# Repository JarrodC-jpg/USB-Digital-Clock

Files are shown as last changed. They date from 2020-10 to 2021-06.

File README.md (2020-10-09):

# USB-Digital-Clock
Usb powered digital clock

Written by: Jarrod Coffin

Press top or bottom button to turn off center lights

To set the time:
1. Press and hold the top button until center lights start blinking
2. Top button adjust the hour, bottom button adjust minutes
3. Press and hold top button to set time, the center lights will stop blinking
4. To back out of time set without saveing press and hold the bottom button

*Note: The time currently gaines a few seconds a day resulting in about a 1 minute time loss over the course of a few days. Still need to squash that timing bug. If you have an idea of how to fix that, create a new branch and take a shot. If it fixes the issue we will merger it to the master.

If you would like a board and parts, contact me at harris.ee.projects@gmail.com

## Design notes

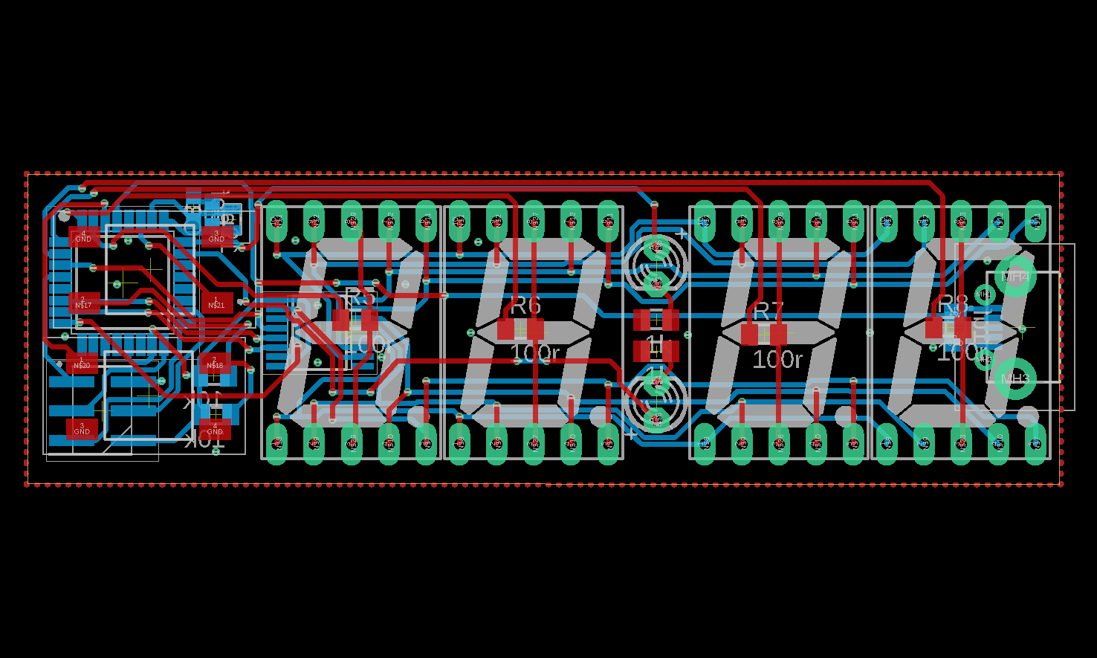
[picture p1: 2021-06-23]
Schematic and Board Files/cloclpcb.png

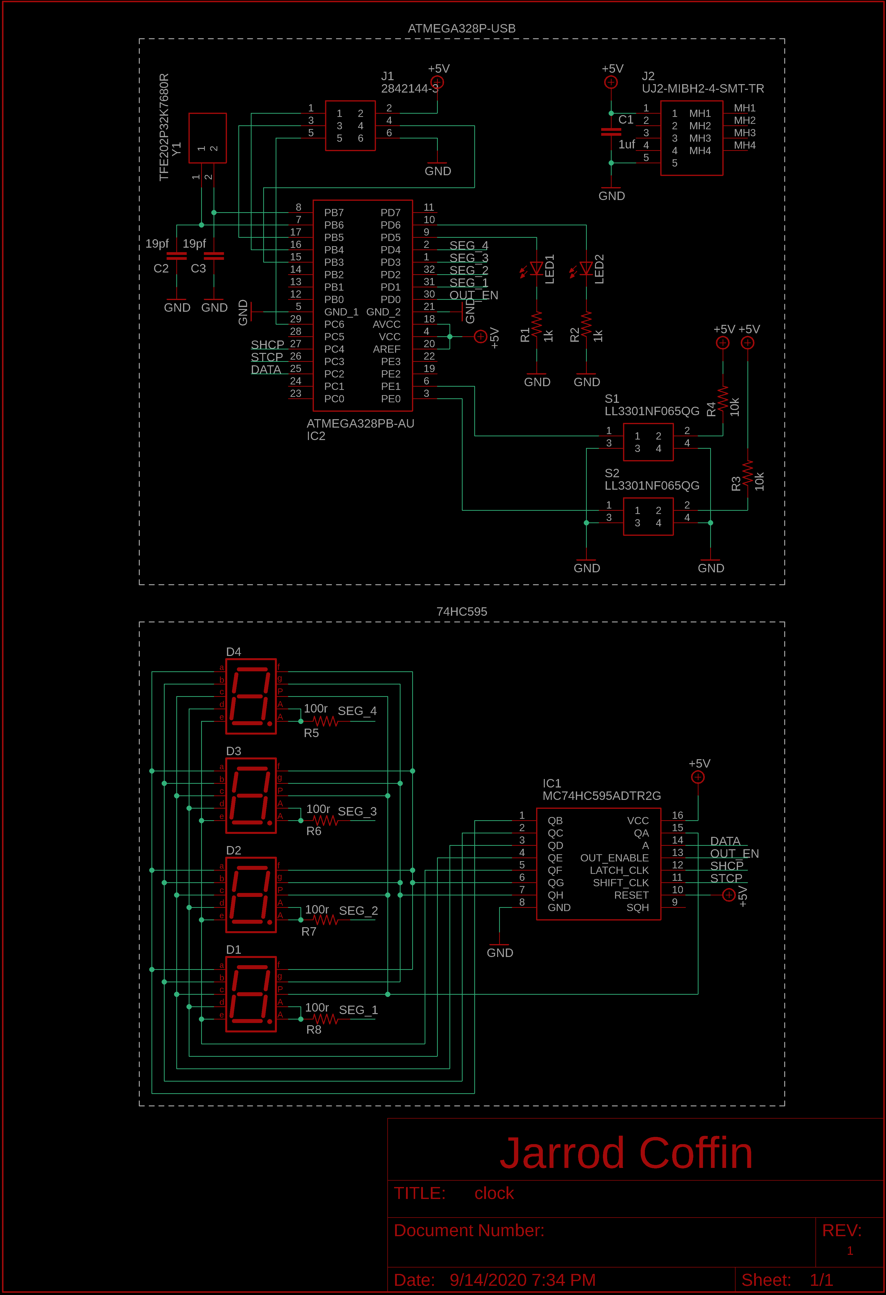
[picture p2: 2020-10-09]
Digital Clock Schem.png

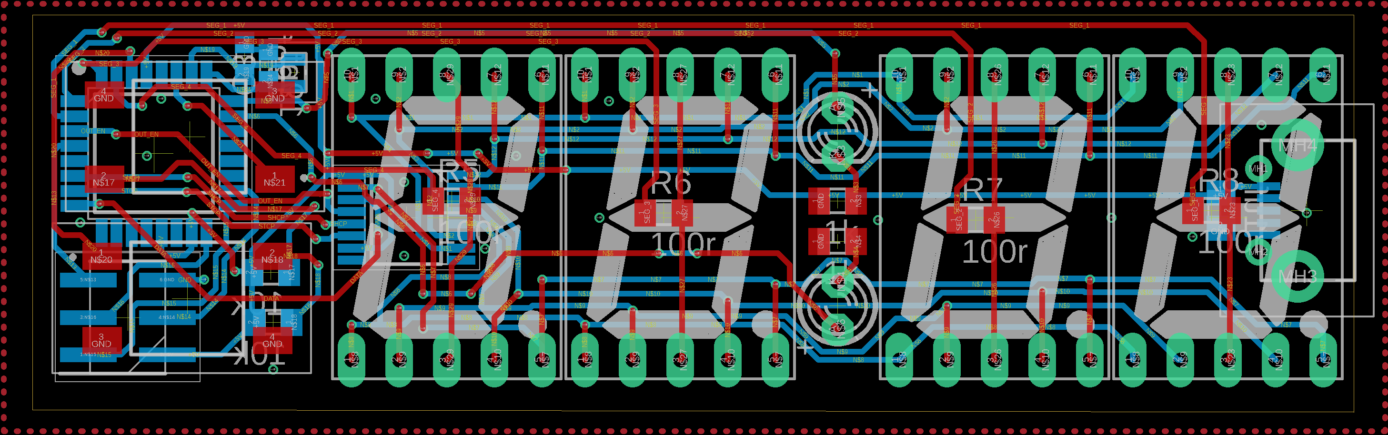
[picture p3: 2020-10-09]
Digital Clock.png

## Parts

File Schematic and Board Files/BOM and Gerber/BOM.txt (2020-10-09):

Partlist exported from Y:/EE_Projects/Clock/Clock/clock.sch at 9/14/2020 6:51 PM

Qty Value              Device             Package                        Parts          Description                                                                                                                          ARROW_PART_NUMBER  ARROW_PRICE-STOCK                                                     DESCRIPTION                                                                                                                          HEIGHT MANUFACTURER_NAME MANUFACTURER_PART_NUMBER MOUSER_PART_NUMBER  MOUSER_PRICE-STOCK                                                                                               POPULARITY SPICEPREFIX
4                      7SEG-CA            7SEG-13                        D1, D2, D3, D4 7-segment DISPLAY                                                                                                                                                                                                                                                                                                                                                                                                                                                                                                                                                               
2                      C-EUC0603          C0603                          C2, C3         CAPACITOR, European symbol                                                                                                                                                                                                                                                                                                                                                                                                                                                                                                                                73         C          
2                      LED3MM             LED3MM                         LED1, LED2     LED                                                                                                                                                                                                                                                                                                                                                                                                                                                                                                                                                                             
4   100r               R-US_R0805         R0805                          R5, R6, R7, R8 RESISTOR, American symbol                                                                                                                                                                                                                                                                                                                                                                                                                                                                                                                                                       
2   10k                R-US_R0805         R0805                          R3, R4         RESISTOR, American symbol                                                                                                                                                                                                                                                                                                                                                                                                                                                                                                                                                       
2   1k                 R-US_R0805         R0805                          R1, R2         RESISTOR, American symbol                                                                                                                                                                                                                                                                                                                                                                                                                                                                                                                                                       
1   1uf                C-EUC0805          C0805                          C1             CAPACITOR, European symbol                                                                                                                                                                                                                                                                                                                                                                                                                                                                                                                                88         C          
1   2842144-3          2842144-3          HUSSP6W50P200_2X3_600X400X590P J1             Board to Board & Mezzanine Connectors 6P,2MM,BRK HDR,DRVT, SMD,0.76AU,TR W/CAP                                                       2842144-3                                                                                Board to Board & Mezzanine Connectors 6P,2MM,BRK HDR,DRVT, SMD,0.76AU,TR W/CAP                                                       mm     TE Connectivity   2842144-3                571-2842144-3       https://www.mouser.co.uk/ProductDetail/TE-Connectivity/2842144-3?qs=Cb2nCFKsA8oUVnOWAoq9Vg%3D%3D                                       
1   ATMEGA328PB-AU     ATMEGA328PB-AU     QFP80P900X900X120-32N          IC2            ATMEL - ATMEGA328PB-AU - MCU, 8BIT, ATMEGA, 20MHZ, TQFP-32                                                                           ATMEGA328PB-AU     https://www.arrow.com/en/products/atmega328pb-au/microchip-technology ATMEL - ATMEGA328PB-AU - MCU, 8BIT, ATMEGA, 20MHZ, TQFP-32                                                                           1.2mm  Microchip         ATMEGA328PB-AU           556-ATMEGA328PB-AU  https://www.mouser.co.uk/ProductDetail/Microchip-Technology-Atmel/ATMEGA328PB-AU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                       
2   LL3301NF065QG      LL3301NF065QG      LL3301NF065QG                  S1, S2         E-SWITCH - LL3301NF065QG - TACTILE SW, SPST, 0.05A, 12VDC, SOLDER                                                                    LL3301NF065QG                                                                            E-SWITCH - LL3301NF065QG - TACTILE SW, SPST, 0.05A, 12VDC, SOLDER                                                                    4mm    E-Switch          LL3301NF065QG            612-LL3301NF065QG   https://www.mouser.co.uk/ProductDetail/E-Switch/LL3301NF065QG?qs=QtyuwXswaQiWhwgY68YTTw%3D%3D                                          
1   MC74HC595ADTR2G    MC74HC595ADTR2G    SOP65P640X120-16N              IC1            8-Bit Shift Register SER-SER/PAR TSSOP16 MC74HC595ADTR2G, 8-stage Shift Register, Serial to Serial/Parallel, 2  6 V, 16-Pin TSSOP-16                                                                                          8-Bit Shift Register SER-SER/PAR TSSOP16 MC74HC595ADTR2G, 8-stage Shift Register, Serial to Serial/Parallel, 2  6 V, 16-Pin TSSOP-16 1.2mm  ON Semiconductor  MC74HC595ADTR2G          863-MC74HC595ADTR2G https://www.mouser.com/Search/Refine.aspx?Keyword=863-MC74HC595ADTR2G                                                                  
1   TFE202P32K7680R    TFE202P32K7680R    TFE202P32K7680R                Y1             Crystals 32.768kHz 12.5pF 20ppm -40C +85C                                                                                            TFE202P32K7680R    https://www.arrow.com/en/products/tfe202p32k7680r/cts                 Crystals 32.768kHz 12.5pF 20ppm -40C +85C                                                                                            0.6mm  CTS               TFE202P32K7680R          774-TFE202P32K7680R https://www.mouser.co.uk/ProductDetail/CTS-Electronic-Components/TFE202P32K7680R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                       
1   UJ2-MIBH2-4-SMT-TR UJ2-MIBH2-4-SMT-TR UJ2MIBH24SMTTR                 J2             CONN RCPT USB2.0 MICRO B SMD R/A                                                                                                     UJ2-MIBH2-4-SMT-TR https://www.arrow.com/en/products/uj2-mibh2-4-smt-tr/cui-devices      CONN RCPT USB2.0 MICRO B SMD R/A                                                                                                     2.5mm  CUI Devices       UJ2-MIBH2-4-SMT-TR       490-UJ2-MIBH2-4-SMT https://www.mouser.co.uk/ProductDetail/CUI-Devices/UJ2-MIBH2-4-SMT-TR?qs=5mqXD9RfOg1yxHIpPvPxvQ%3D%3D

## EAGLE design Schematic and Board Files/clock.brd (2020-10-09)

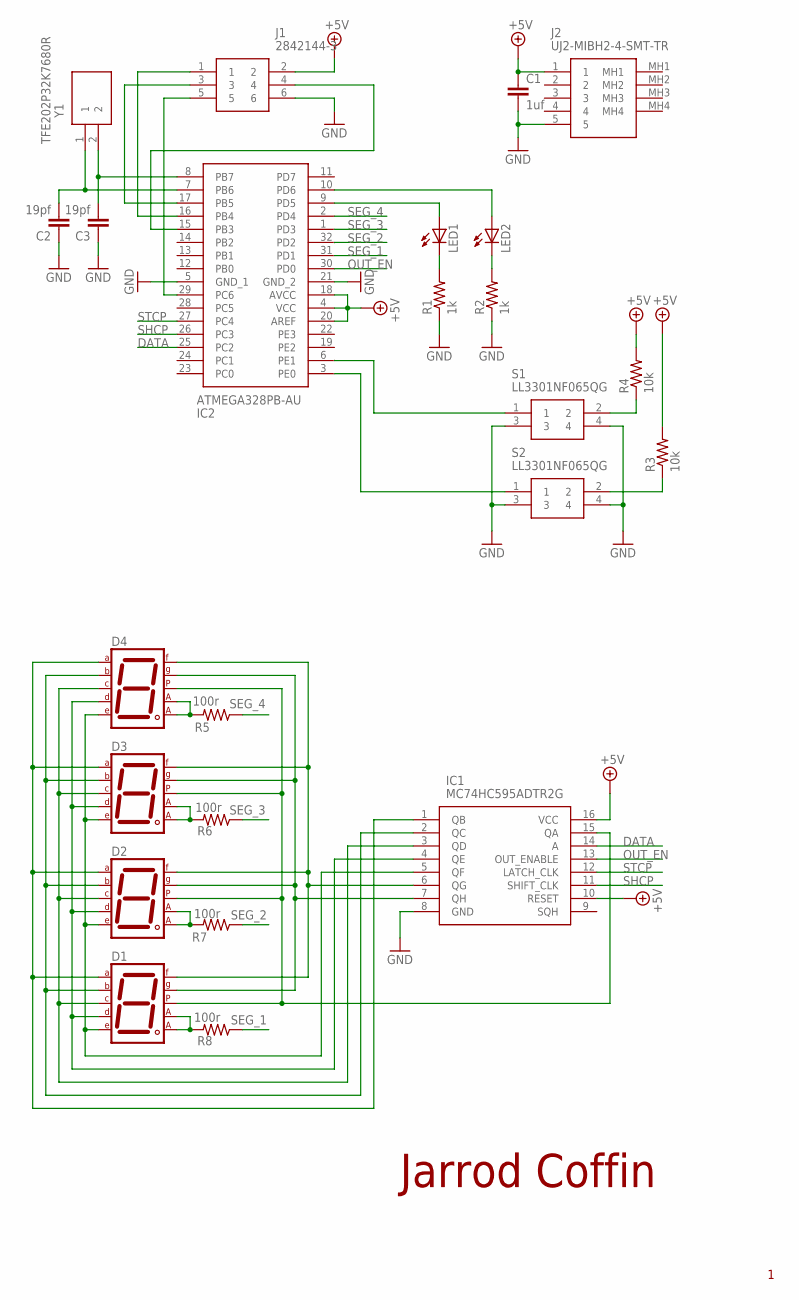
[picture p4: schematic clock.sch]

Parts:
C1: 1uf; C0805
C2, C3: 19pf; C0603
D1, D2, D3, D4: 7SEG-CA; 7SEG-13
IC1: MC74HC595ADTR2G; SOP65P640X120-16N
IC2: ATMEGA328PB-AU; QFP80P900X900X120-32N
J1: 2842144-3; HUSSP6W50P200_2X3_600X400X590P
J2: UJ2-MIBH2-4-SMT-TR; UJ2MIBH24SMTTR
LED1, LED2: LED3MM
R1, R2: 1k; R0805
R3, R4: 10k; R0805
R5, R6, R7, R8: 100r; R0805
S1, S2: LL3301NF065QG
Y1: TFE202P32K7680R

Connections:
+5V: C1.1, IC1.10 (RESET), IC1.16 (VCC), IC2.4 (VCC), IC2.18 (AVCC), IC2.20 (AREF), J1.2, J2.1, R3.2, R4.2
DATA: IC1.14 (A), IC2.25 (PC2)
GND: C1.2, C2.1, C3.1, IC1.8 (GND), IC2.5 (GND_1), IC2.21 (GND_2), J1.6, J2.5, R1.1, R2.1, S1.3, S1.4, S2.3, S2.4
unnamed: D1.10 (G), D2.10 (G), D3.10 (G), D4.10 (G), IC1.7 (QH)
unnamed: D1.9 (F), D2.9 (F), D3.9 (F), D4.9 (F), IC1.6 (QG)
unnamed: LED1.K (C), R1.2
unnamed: LED2.K (C), R2.2
unnamed: IC2.9 (PD5), LED1.A
unnamed: IC2.10 (PD6), LED2.A
unnamed: D1.5 (DP), D2.5 (DP), D3.5 (DP), D4.5 (DP), IC1.15 (QA)
unnamed: D1.1 (E), D2.1 (E), D3.1 (E), D4.1 (E), IC1.5 (QF)
unnamed: D1.2 (D), D2.2 (D), D3.2 (D), D4.2 (D), IC1.4 (QE)
unnamed: D1.4 (C), D2.4 (C), D3.4 (C), D4.4 (C), IC1.3 (QD)
unnamed: D1.6 (B), D2.6 (B), D3.6 (B), D4.6 (B), IC1.2 (QC)
unnamed: D1.7 (A), D2.7 (A), D3.7 (A), D4.7 (A), IC1.1 (QB)
unnamed: IC2.29 (PC6), J1.5
unnamed: IC2.15 (PB3), J1.4
unnamed: IC2.16 (PB4), J1.1
unnamed: IC2.17 (PB5), J1.3
unnamed: R4.1, S1.2
unnamed: R3.1, S2.2
unnamed: C2.2, IC2.7 (PB6), Y1.1
unnamed: IC2.3 (PE0), S2.1
unnamed: IC2.6 (PE1), S1.1
unnamed: D1.3 (CA1), D1.8 (CA2), R8.2
unnamed: C3.2, IC2.8 (PB7), Y1.2
unnamed: D2.3 (CA1), D2.8 (CA2), R7.2
unnamed: D3.3 (CA1), D3.8 (CA2), R6.2
unnamed: D4.3 (CA1), D4.8 (CA2), R5.2
OUT_EN: IC1.13 (OUT_ENABLE), IC2.30 (PD0)
SEG_1: IC2.31 (PD1), R8.1
SEG_2: IC2.32 (PD2), R7.1
SEG_3: IC2.1 (PD3), R6.1
SEG_4: IC2.2 (PD4), R5.1
SHCP: IC1.11 (SHIFT_CLK), IC2.26 (PC3)
STCP: IC1.12 (LATCH_CLK), IC2.27 (PC4)

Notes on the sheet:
Jarrod Coffin

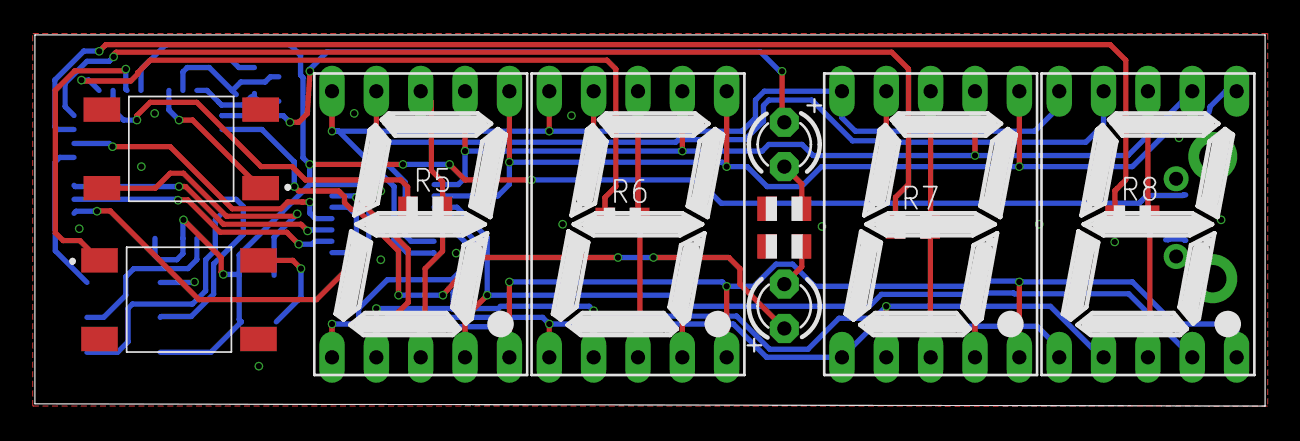
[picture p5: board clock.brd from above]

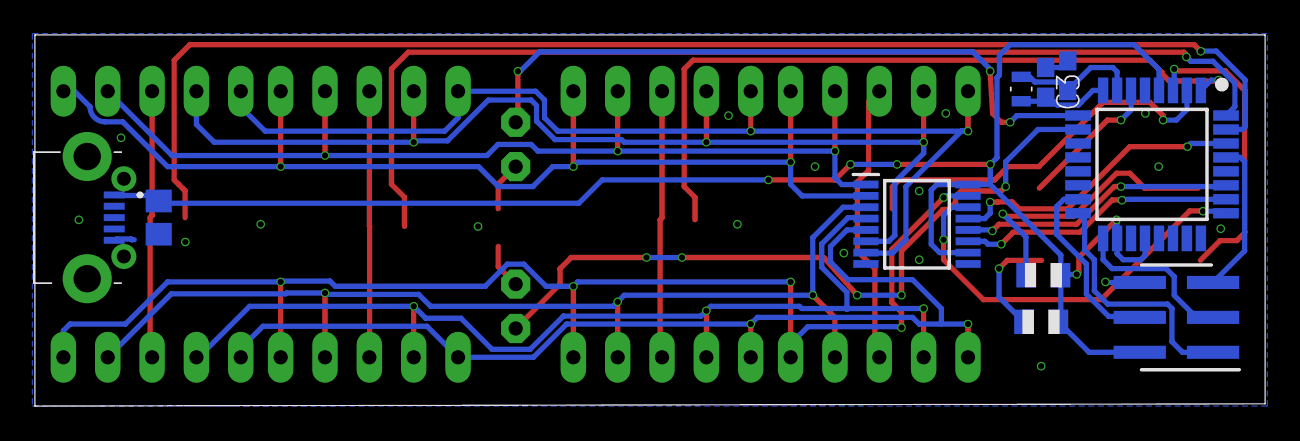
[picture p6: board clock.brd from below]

Board: 2 copper layers, 70.5 x 21.3 mm, 24 parts (10 on the bottom side), 36 nets.

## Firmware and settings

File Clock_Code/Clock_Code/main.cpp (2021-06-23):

/*
 * Clock_Code.cpp
 *
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
 * Created: 10/1/2020 1:28:43 PM
 * Author : Jarrod Coffin
 */ 

#include <avr/io.h>
#include "Includes/Header/display.h"
#include "Includes/Header/millis.h"
#include "Includes/Header/Functions.h"
#include "Includes/Header/_74HC595.h"

// Main code
int main(void)
{
	RTC_Init();
	millisInit();
	switch_init();
	init_74hc595();
	initDisp();
	blinkCOLON(OFF);
	
	uint8_t lastminutes = ~minutes;
	uint8_t lasthours = ~hours;
	uint8_t lastseconds = ~seconds;
	uint8_t dispSeconds = 0;
	uint16_t secondTimer = 0;
	uint16_t dispSecondTime = 5000;
	
    while (1) 
    {
		uint8_t press_top = switch_read(switch_top);
		uint8_t press_bottom = switch_read(switch_bottom);
		
		switch(press_top){
			
			case SINGLE:
				PORTD ^= COLON;
			break;
			
			case HOLD:
				set_time();
			break;
		
		}
		
		switch(press_bottom){
			
			case SINGLE:
				PORTD ^= COLON;
			break;
			
			case HOLD:
				dispSeconds = 1;
				secondTimer = millis;
				
			break;			
		
		}
		
		while(dispSeconds){
			if (millis - secondTimer > dispSecondTime) dispSeconds = 0;
			if (seconds != lastseconds){
				lastseconds = seconds;
				convertNum(seconds, dispSecond);
			}
			setDisp(CLEAR,CLEAR,dispSecond[1],dispSecond[0]);
		}
		
		
		if (minutes != lastminutes || hours != lasthours){
			
			lastminutes = minutes;
			lasthours = hours;
			convertNum(minutes, dispMinutes);
			convertNum(hours, dispHours);

		}
		
		if(hours < 10)setDisp(CLEAR,dispNum[dispHours[0]],dispNum[dispMinutes[1]],dispNum[dispMinutes[0]]);
		else setDisp(dispNum[dispHours[1]],dispNum[dispHours[0]],dispNum[dispMinutes[1]],dispNum[dispMinutes[0]]);
    
	}
}

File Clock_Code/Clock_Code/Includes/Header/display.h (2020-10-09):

/* 
* display.h
*
* This file is part of Clock_Code.
*
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
* Created: 10/1/2020 12:25:54 AM
* Author: Jarrod Coffin
*/


#ifndef __DISPLAY_H__
#define __DISPLAY_H__

#define F_CPU 8000000UL

#include <avr/io.h>
#include "util/delay.h"
#include "_74HC595.h"

// 7 Seg Select
#define Seg_ONE		(1<<1)
#define Seg_TEN		(1<<2)
#define Seg_HUNDRED (1<<3)
#define Seg_THOU	(1<<4)
#define COLON		(3<<5)
#define COLON_CHECK (COLON & PIND)
#define Seg_Clear  PORTD = 0x00 | COLON_CHECK
#define Seg_ONE_ON PORTD = Seg_ONE | COLON_CHECK
#define Seg_TEN_ON PORTD = Seg_TEN | COLON_CHECK
#define Seg_HUNDRED_ON PORTD = Seg_HUNDRED | COLON_CHECK
#define Seg_THOU_ON PORTD = Seg_THOU | COLON_CHECK

#define DOT		 ~(1<<7)
#define CLEAR	0xff
//							 .abcdefg
#define ZERO	(uint8_t)~(0b01111110)
#define ONE		(uint8_t)~(0b00110000)
#define TWO		(uint8_t)~(0b01101101)
#define THREE	(uint8_t)~(0b01111001)
#define FOUR	(uint8_t)~(0b00110011)
#define FIVE	(uint8_t)~(0b01011011)
#define SIX		(uint8_t)~(0b01011111)
#define SEVEN	(uint8_t)~(0b01110010)
#define EIGHT	(uint8_t)~(0b01111111)
#define NINE	(uint8_t)~(0b01111011)



extern uint8_t dispNum[10];

void initDisp();
void setDisp(uint8_t oneData, uint8_t tenData, uint8_t hunData, uint8_t thouData);
void clearDisp();


#endif //__DISPLAY_H__

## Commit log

2020-10-09 Adding all files
    [clock.brd, clock.sch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]
2020-10-09 File management
    [copper_bottom.gbr, copper_top.gbr, drill_1_16.xln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]
2021-06-23 trying to fix shit
    [main.cpp]

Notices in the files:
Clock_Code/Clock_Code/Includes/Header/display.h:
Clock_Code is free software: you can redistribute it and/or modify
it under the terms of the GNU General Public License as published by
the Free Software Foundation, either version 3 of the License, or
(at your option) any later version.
